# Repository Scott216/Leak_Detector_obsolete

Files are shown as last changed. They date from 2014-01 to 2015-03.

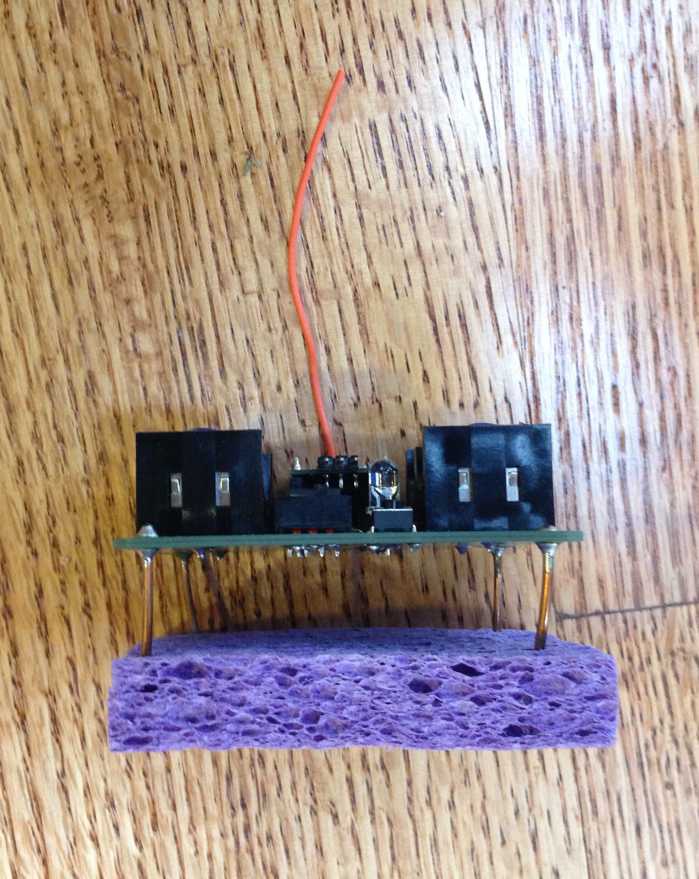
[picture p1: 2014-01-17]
Photos/Leak_Detector 7.jpg

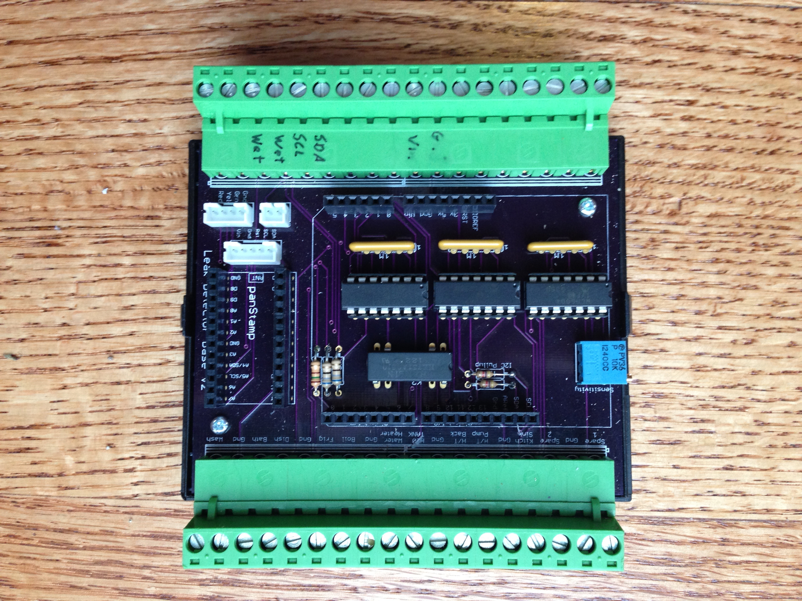
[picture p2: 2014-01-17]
Photos/Leak_Detector 4.jpg

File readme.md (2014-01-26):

This project detects water and sends out  Tweet if water is detected.  The main boards is an Arduino Leonardo with an Ethernet Shield.  The moisture sensors are hard-wired to the PCB.  When hard wiring is not practical, it uses a couple of Panstamps which provide wireless communication.  A Panstamp is basically and Arduino Pro-mini with a wireless radio.  

I chose Leonardo because I needed an Arduino without the headers installed.  The Ethernet shield is actually soldered to the Leonardo with the Ethernet Shield's pins sticking through the Leonardo.  They are still plenty long enough so the Leonardo/Ethernet sandwich can be plugged into the headers on the PCB.

To make the water detector sensor, take a dried out sponge and insert two 14 GA solid copper wires, about an inch apart.  I like to cut copper wire at an angle so it forms a sharp point - this makes it easier to insert into the sponge.  Use small gauge stranded wire to connect the sponge to terminal strip. When sponge is dry it appears as an open circuit. When wet it's varies from 30k to 300k ohms.  I have [sample op-amp circuit](https://www.circuitlab.com/circuit/ayhr2v/water-detector-v2/) circuitlab.com.

Use a MCP6004 Op Amp. Need the Op-amp because the impedance of the sponge is high and you get false readings if you wire directly to an Arduino. I'm using the op amp as a comparator.

Main board leak detector BOM

    1x OKW Enclosure B6504112 $9.77
        PCB Board specs 3.87" x 3.22". position screw terminal holes 0.27" from edge
        2x M2.5 x 6mm Screws to mount PCB to OKW Enclosure
        2x 18 position plug header, PCB Side CTB9358/18AO $2.14
        2x 18 Position screw terminal CTB9208/18 $5.84 
    1x Arduino Leonardo - without headers
    1x Ethernet Shield]
    1x panStamp - http://www.panstamp.com/products/wirelessarduino
    1x JST PH 5-position header P/N B5B-PH-K-S, Digikey 455-1707-ND for OLED Display, (JST Data Sheet)
    1x JST PH 5-wire cable Sparkfun PRT-09917, JST # PHR-5, Crimp pin SPH-002T-P0.5S
    1x JST PH 4-position header P/N B4B-PH-K-S, Digikey 455-1706-ND for LEDs
    1x JST PH 4-wire cable Sparkfun PRT-09916, JST # PHR-4, Crimp pin SPH-002T-P0.5S
    1x JST PH 2-position header P/N B2B-PH-K-S, Digikey 455-1704-ND for on-off switch
    1x JST PH 2-wire cable Sparkfun PRT-09914, JST # PHR-2, Crimp pin SPH-002T-P0.5S
    1x OLED 128 x 32 I2C Display, Adafruit 931
    1x Reed Relay, Hamlin HE751A0510, Digikey HE124-ND
    3x MCP6004 Op amp Digikey MCP6004-I/P-ND
    3x Resistor network 1MΩ Bourns P/N 4606X-101-105LF, Digikey 4606X-1-105LF-ND. (cut off lead on pin 6)
    2x 330Ω 1/4 watt resistors
    2x 4.7kΩ 1/4 watt resistors
    2x 68Ω 1/4 watt resistors
    1x 150Ω 1/4 watt resistor
    1x 10k trimmer Pot,Digikey 490-2856-ND
    1x On-Off Switch, CW Industries P/N GPB040B05BR, Digikey SW632-ND
    1x Yellow LED 2 volts, 20 mA, Bivar P/N PM3YDW12.0, Digikey 492-1617-ND
    1x Red LED 2.1 volts, 20 mA, Bivar P/N PM3RDW12.0, Digikey 492-1616-ND
    1x Green LED 2.1 volts, 20 mA, Bifar P/N PM3GDW12.0, Digikey 492-1612-ND
    1x 10-pin Header for Leonardo, Digikey S7043-ND
    2x 8-pin Header for Leonardo, Digikey S7041-ND
    1x 6-pin Header for Leonardo, Digikey S7039-ND
    2x 12-pin Headers for panStamp, Digikey S7045-ND 

Remote Wireless Detector BOM

    1 MCP601 Op Amp Digikey MCP601-I/P-ND
    8 pin DIP socket Sparkfun PRT-07937
    2 Battery Holders, Digikey 708-1412-ND
    2 CR123 batteries
    1 470k ohm resistor
    1 Panstamp
    1 slide switch Sparkfun COM-00102
    2 5.6 ohm resistor for green & blue led in RGB LED
    1 68 ohm resistor for for red in RGB LED
    1 RGB LED Sparkfun COM-00105
    1 Pushbutton switch, Sparkfun COM-00097
    1 OneWire temp sensor DS18B20
    2 12-pin headers for PanStamp

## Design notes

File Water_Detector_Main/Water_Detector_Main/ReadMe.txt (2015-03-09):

The sketch gets time from an NPT server.  Water detect notifications and low battery are sent out via Twitter.

See this Arduino Thread forum on a discussion on reading inputs and using an Op Amp 
  http://arduino.cc/forum/index.php/topic,90671.msg682130.html#msg682130

I2C Data packet structure
byte 0: panStamp Tx ID
byte 1: Tx online: 0 = offline, 1 = online
byte 2: Wet/Dry Status: 0 = Dry, 1 = Wet
byte 3-4: temperature F
Byte 5-6: battery voltage (millivolts)
Byte 7-8: Spare
Byte 9: checksum

Put sensors in a class.  One class for sensors, then a wired subclass and wireless subclass
Create an array of class objects

Properties:
 For both wired and wireless
   Is wet input - live wet/dry status
   Is wet status - used to trigger dry to wet transition
   Is wet output - wet dry status after some delay
   Name - character array of sensor location, this text can be used for messages on OLED and twitter
   Dry out delay - timer used to let sponge dry out.  Elimantes cycling when sponge is drying out
   Wet delay - delay used to make sure sponge is really wet.  Elimantes cycling when sponge first gets wet
   
 For wireless only:
   Tx Address
   Tx is online
   Temperature
   Battery volts
   Flag - low volts message
   Flag - low temp message
   Flag - sensor offline message

Methods/Actions
  For both wired and wireless
    Send message when water is detected
    Send message when sponge dries up

  For wireless only
    Send message if Tx is offline
    Send messaeg if Tx goes back online
    Send message if battery is low
    Send message if temp is low
    Send message for weekly heartbeat

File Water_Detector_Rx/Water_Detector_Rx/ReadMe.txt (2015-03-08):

Water_Detector_Rx

The receiving panStamp is communicating with the Leonardo via I2C.  The Leonardo is the master and will make a request for the data.  The panStamp will then transmit this as one long array of bytes. Sketch is using DSS's I2C.h library for the I2C master, not Wire.h library.

I2C Data packet structure
byte 0: panStamp Tx ID
byte 1: Tx online: 0 = offline, 1 = online
byte 2: Wet/Dry Status: 0 = Dry, 1 = Wet
byte 3-4: temperature F
Byte 5-6: battery voltage (millivolts)
Byte 7-8: Spare
Byte 9: checksum

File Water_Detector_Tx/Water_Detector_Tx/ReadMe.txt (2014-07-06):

Water_Detector_Tx

A panStamp should be able to run for a couple months on one CR123 battery. 

The panStamps transmit wet/dry status, their ID, battery voltage and temperature.

They sleep for 8 seconds, wake up for 1/2 second to transmit, then repeat.

Simple panStamp test - doesn't use SWAP protocal
Source: http://www.panstamp.org/forum/showthread.php?tid=22

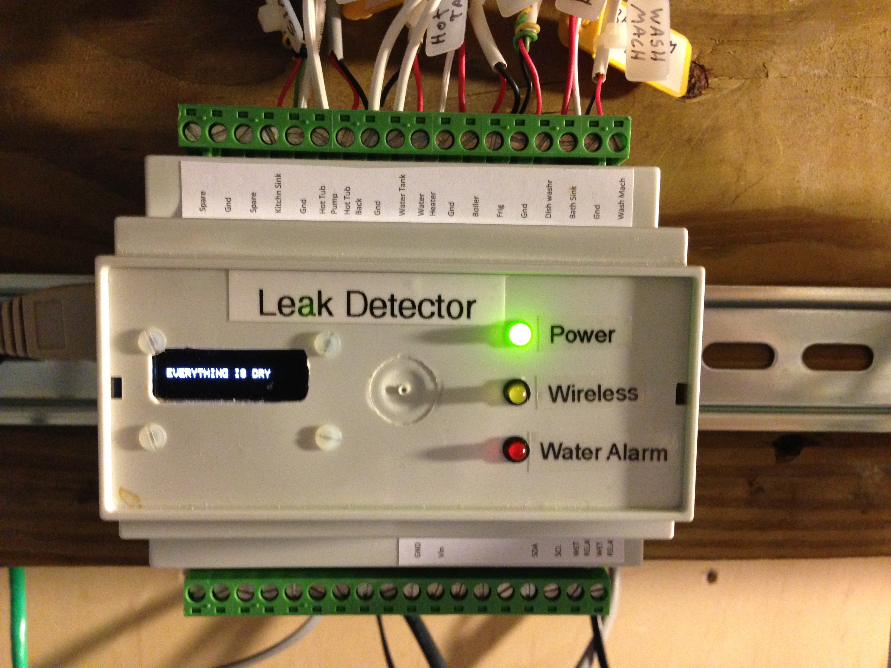
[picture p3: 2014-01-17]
Photos/Leak_Detector 3.jpg

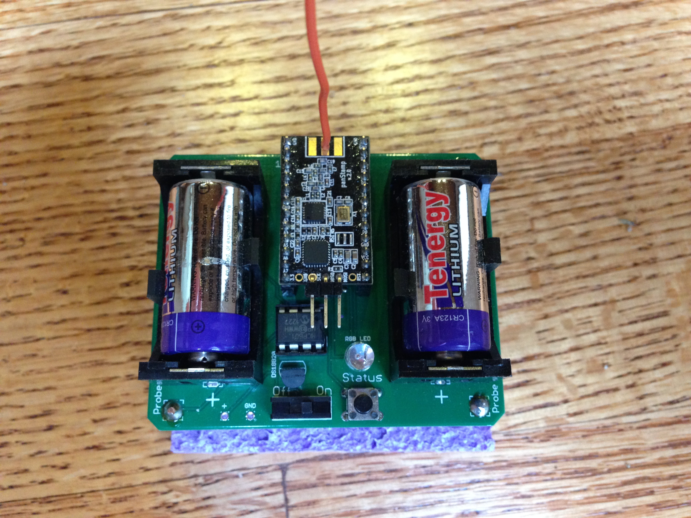
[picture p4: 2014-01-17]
Photos/Leak_Detector 8.jpg

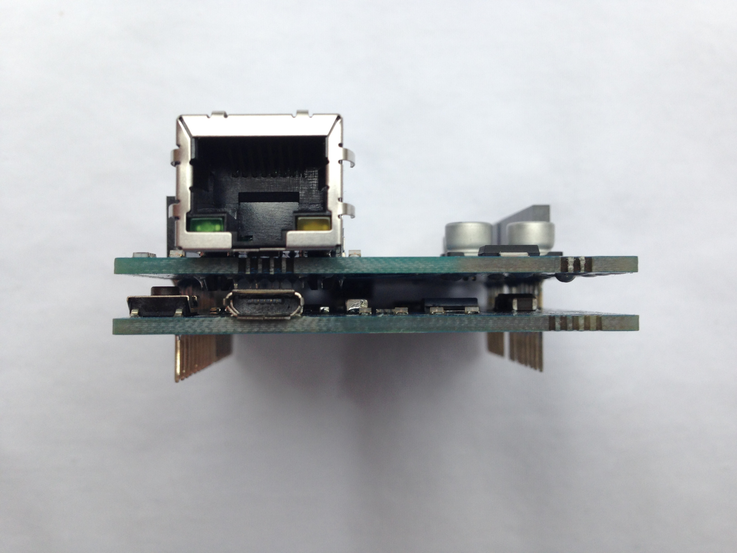
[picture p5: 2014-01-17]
Photos/Leak_Detector 2.jpg

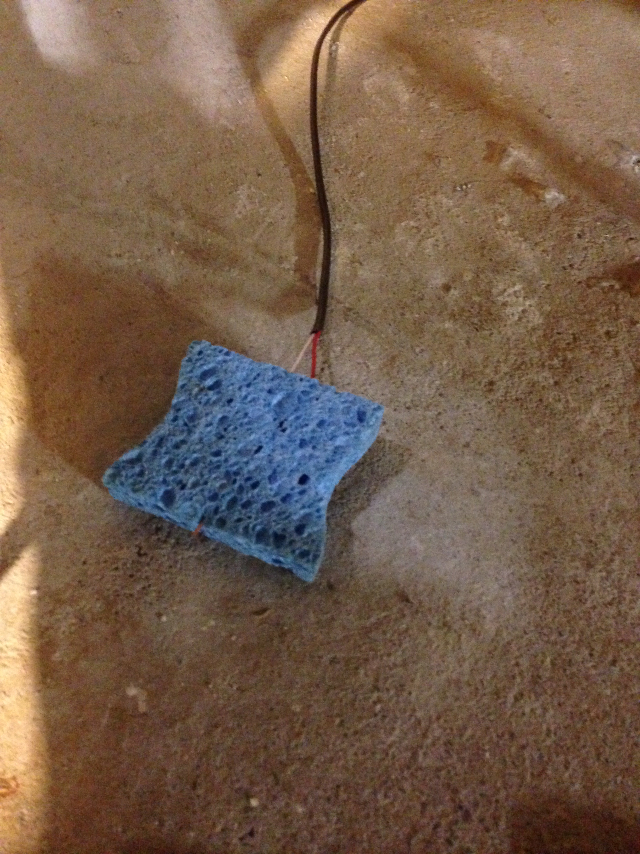
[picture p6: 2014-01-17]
Photos/Leak_Detector 6.jpg

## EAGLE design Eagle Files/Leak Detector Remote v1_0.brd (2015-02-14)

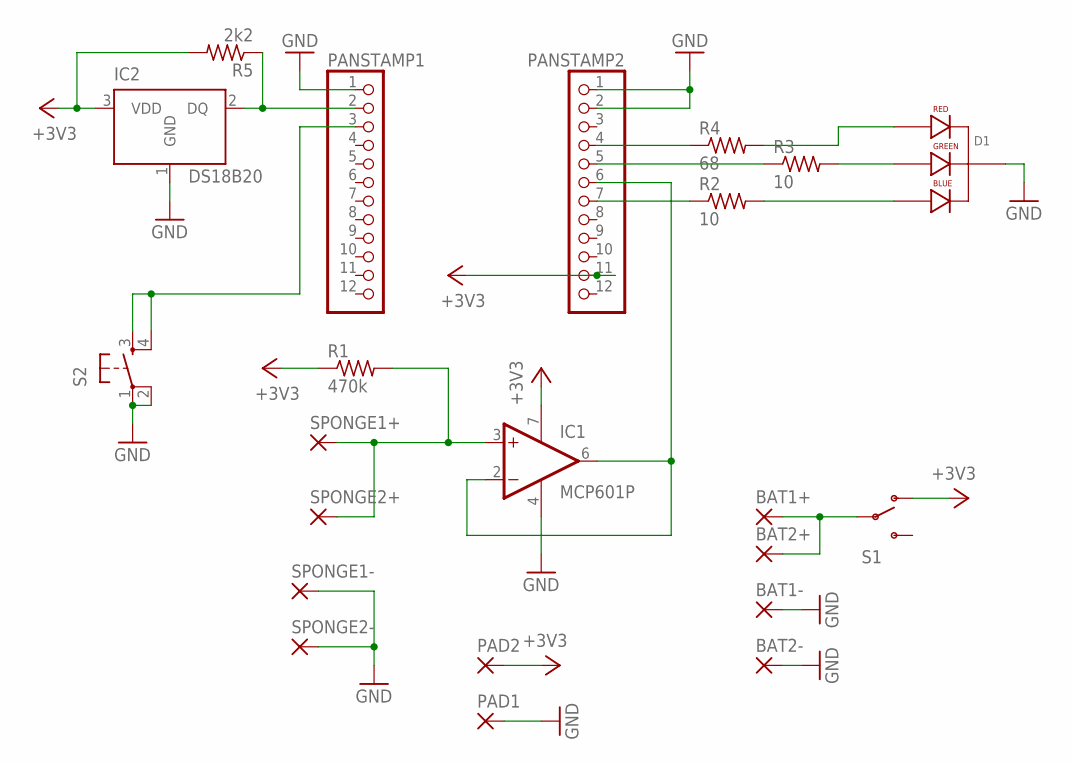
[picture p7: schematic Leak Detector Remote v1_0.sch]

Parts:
BAT1+, BAT1-, BAT2+, BAT2-: 3,81/1,4
D1: LED-RGB-CC-THRUCLEAR; LED-RGB-THRU
IC1: MCP601P; DIL08
IC2: DS18B20; TO-92
PAD1, PAD2: 1,6/0,9
PANSTAMP1, PANSTAMP2: PINHD-1X12; 1X12
R1: 470k; 0204/7
R2, R3: 10; 0204/7
R4: 68; 0204/7
R5: 2k2; 0204/7
S1: SWITCH-SPDTKIT; SWITCH-SPDT_KIT
S2: TAC_SWITCHPTH; TACTILE-PTH
SPONGE1+, SPONGE1-, SPONGE2+, SPONGE2-: 3,81/1,4

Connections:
+3V3: IC1.7 (V+), IC2.3 (VDD), PAD2.1, PANSTAMP2.11, R1.1, R5.2, S1.1 (O)
D3: PANSTAMP2.7, R2.1
D4: IC1.2 (-IN), IC1.6 (OUT), PANSTAMP2.6
D5: PANSTAMP2.5, R3.1
D6: PANSTAMP2.4, R4.1
D8: IC2.2 (DQ), PANSTAMP1.2, R5.1
D9: PANSTAMP1.3, S2.3, S2.4
GND: BAT1-.1, BAT2-.1, D1.2 (CATHODE), IC1.4 (V-), IC2.1 (GND), PAD1.1, PANSTAMP1.1, PANSTAMP2.1, PANSTAMP2.2, S2.1, S2.2, SPONGE1-.1, SPONGE2-.1
unnamed: IC1.3 (+IN), R1.2, SPONGE1+.1, SPONGE2+.1
unnamed: BAT1+.1, BAT2+.1, S1.2
unnamed: D1.1 (RED_CATHODE), R4.2
unnamed: D1.3 (GREEN_CATHODE), R3.2
unnamed: D1.4 (BLUE_CATHODE), R2.2

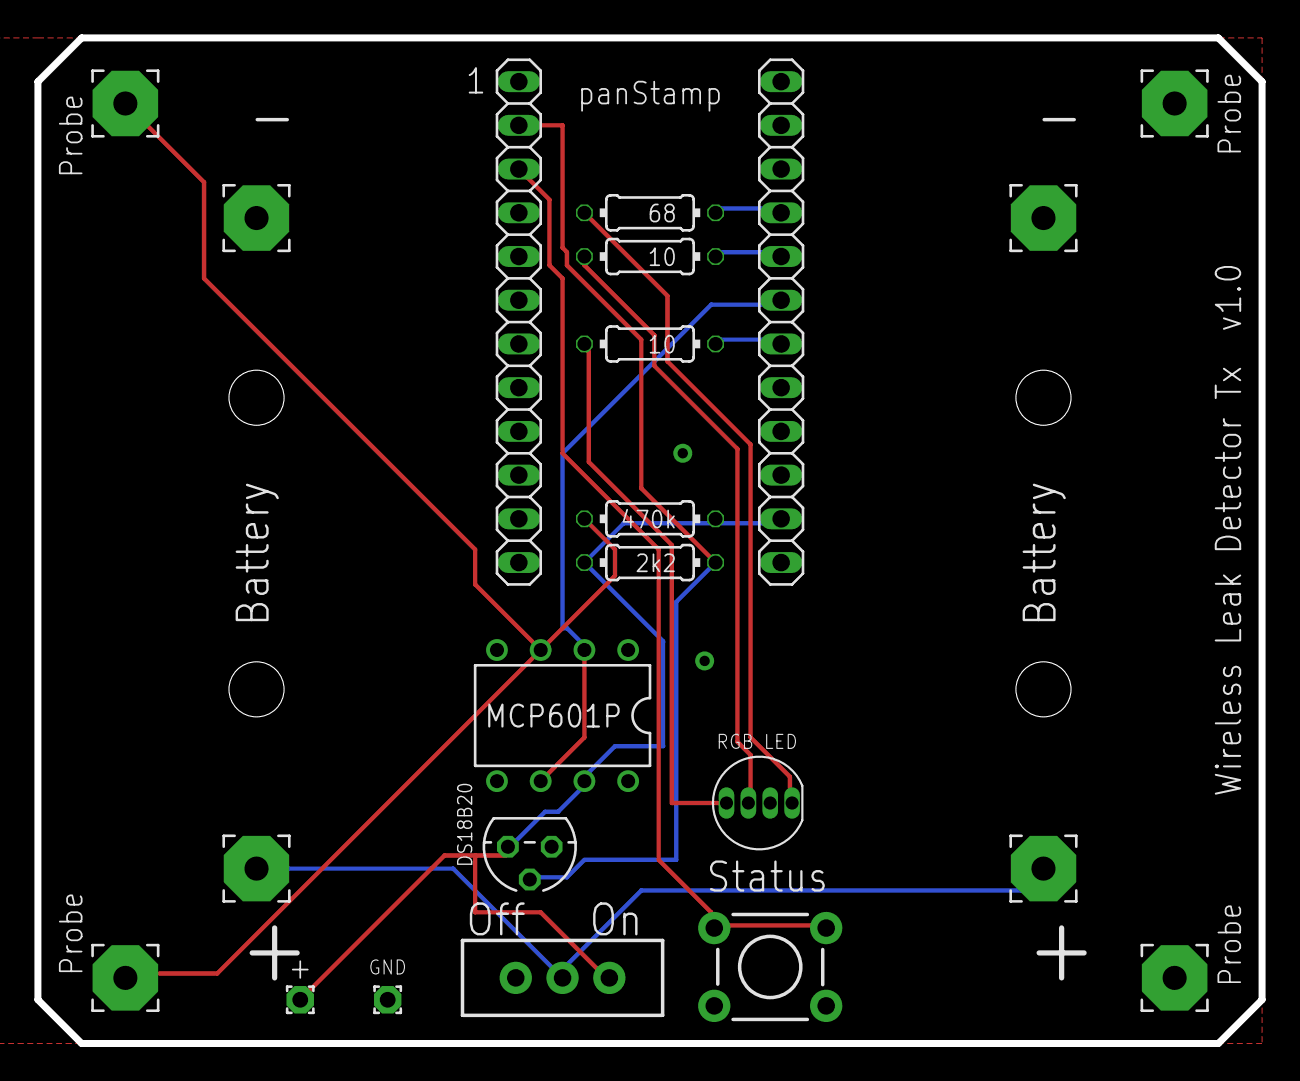
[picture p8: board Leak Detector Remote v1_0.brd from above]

Board: 2 copper layers, 71.1 x 58.4 mm, 22 parts (0 on the bottom side), 13 nets.

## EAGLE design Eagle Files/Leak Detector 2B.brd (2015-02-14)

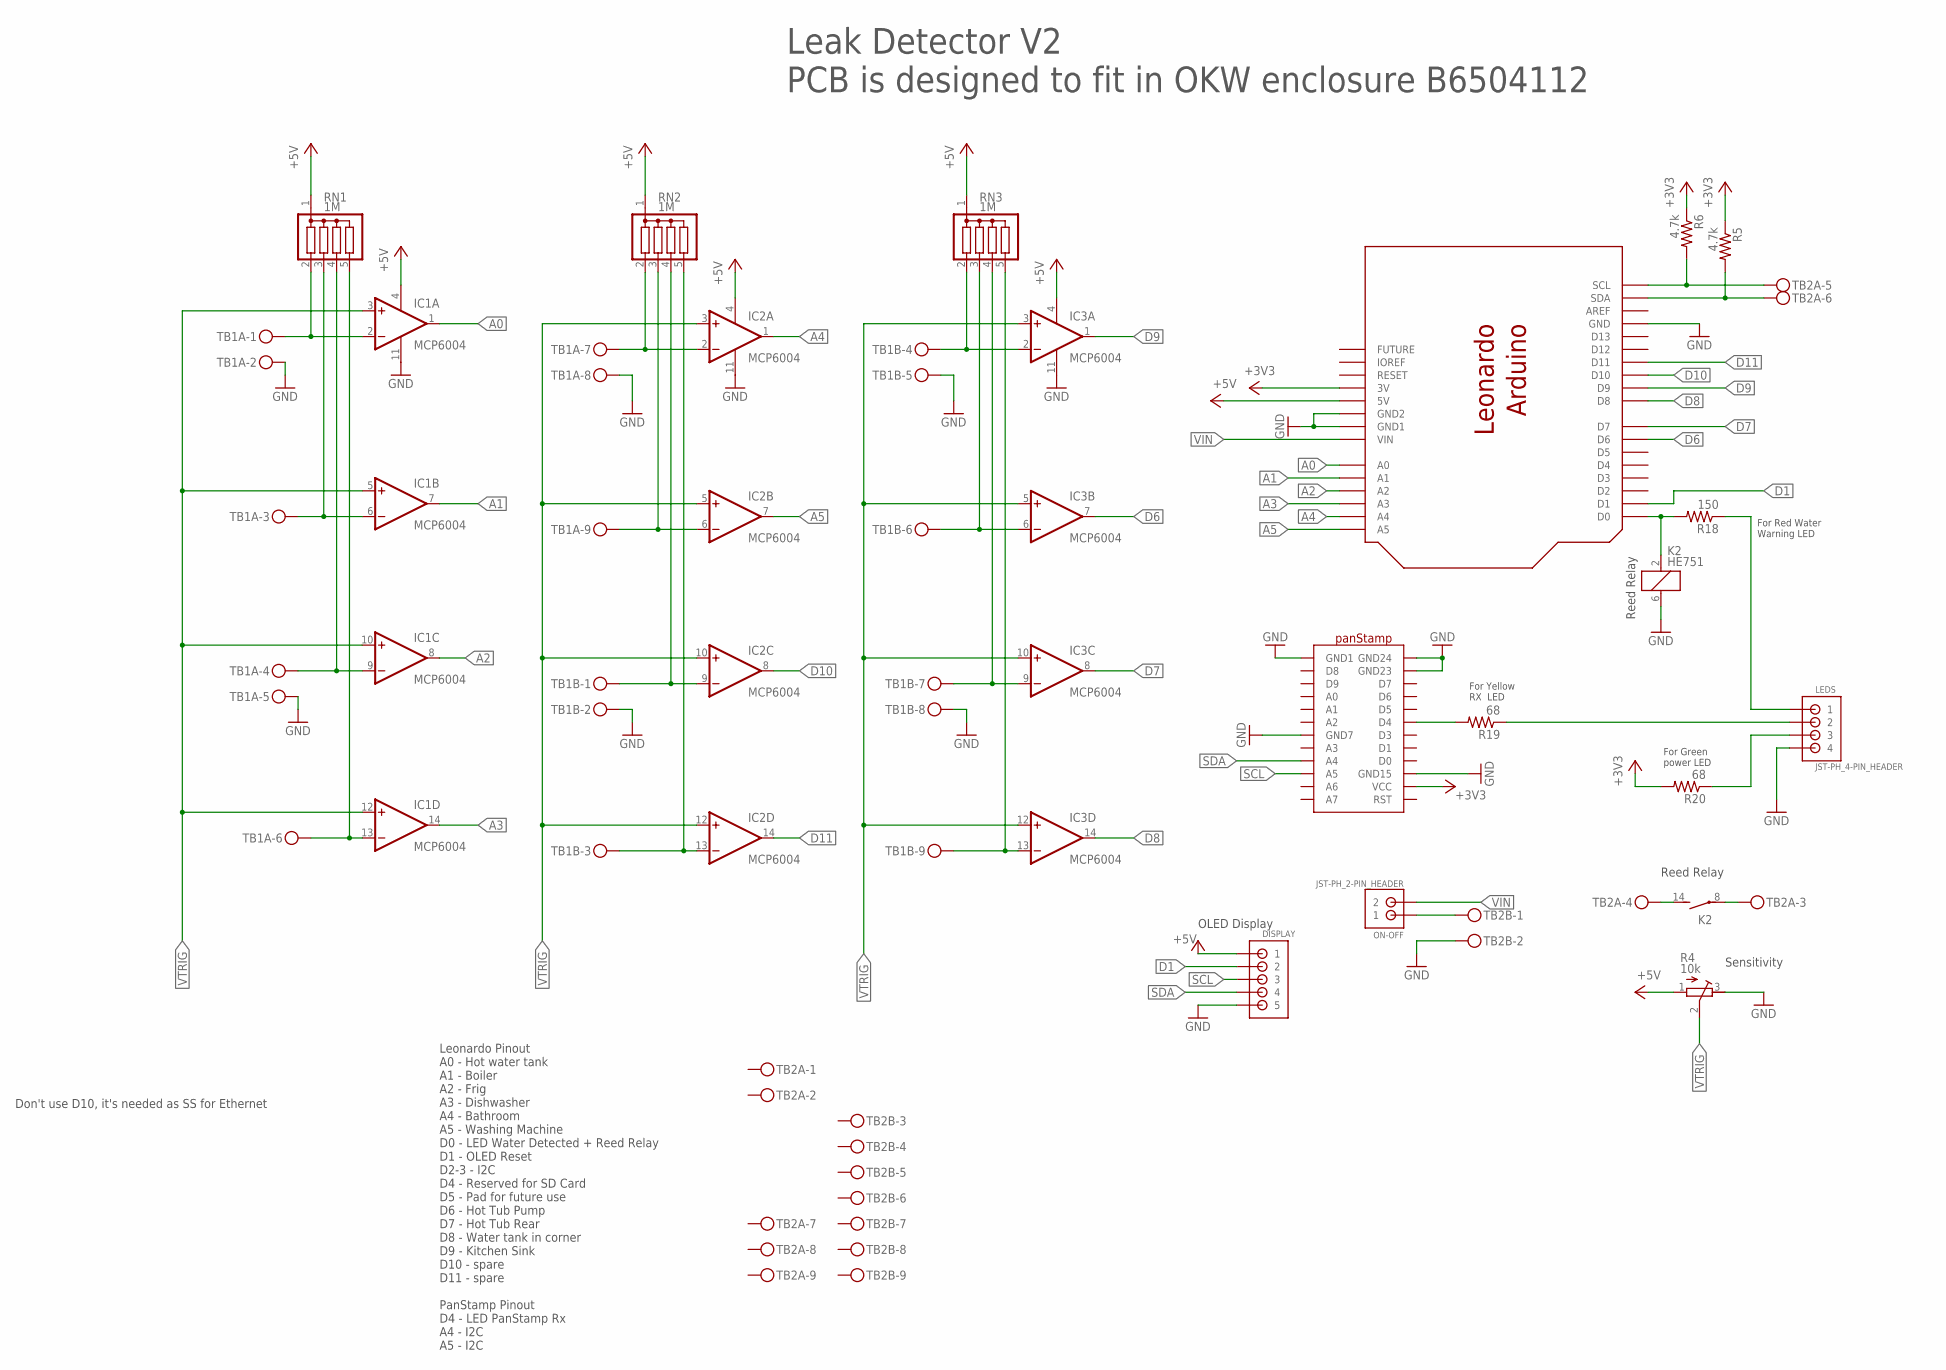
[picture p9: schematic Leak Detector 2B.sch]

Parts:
DISPLAY: JST-PH_5-PIN_HEADER; JST_B5B-PH_HEADER
IC1, IC2, IC3: MCP6004; DIL14
K2: HE751
LEDS: JST-PH_4-PIN_HEADER; JST_B4B-PH_HEADER
ON-OFF: JST-PH_2-PIN_HEADER; JST_B2B-PH_HEADER
R4: 10k; RTRIM3296P
R5, R6: 4.7k; 0207/10
R18: 150; 0207/10
R19, R20: 68; 0207/10
RN1, RN2, RN3: 1M; SIL5
TB1A, TB1B, TB2A, TB2B: MKDSN1,5/9-5,08
U$1: ARDUINO_LEONARDO
U$2: PANSTAMP

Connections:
+3V3: R5.1, R6.1, R20.2, U$1.3V, U$2.VCC
+5V: DISPLAY.P1 (1), IC1.4 (V+), IC2.4 (V+), IC3.4 (V+), R4.1 (E), RN1.1, RN2.1, RN3.1, U$1.5V
A0: IC1.1 (OUT), U$1.A0
A1: IC1.7 (OUT), U$1.A1
A2: IC1.8 (OUT), U$1.A2
A3: IC1.14 (OUT), U$1.A3
A4: IC2.1 (OUT), U$1.A4
A5: IC2.7 (OUT), U$1.A5
BATHROOM: IC2.2 (-IN), RN2.2, TB1A.7
BOILER: IC1.6 (-IN), RN1.3, TB1A.3
D1: DISPLAY.P2 (2), U$1.D1
D6: IC3.7 (OUT), U$1.D6
D7: IC3.8 (OUT), U$1.D7
D8: IC3.14 (OUT), U$1.D8
D9: IC3.1 (OUT), U$1.D9
D10: IC2.8 (OUT), U$1.D10
D11: IC2.14 (OUT), U$1.D11
DISHWASHER: IC1.13 (-IN), RN1.5, TB1A.6
FRIG: IC1.9 (-IN), RN1.4, TB1A.4
GND: DISPLAY.P5 (5), IC1.11 (V-), IC2.11 (V-), IC3.11 (V-), K2.6 (2), LEDS.P4 (4), R4.3 (A), TB1A.2, TB1A.5, TB1A.8, TB1B.2, TB1B.5, TB1B.8, TB2B.2, U$1.GND, U$1.GND$2 (GND2), U$1.GND$3 (GND1), U$2.GND1, U$2.GND7, U$2.GND15, U$2.GND23, U$2.GND24
HAVEPOWER: LEDS.P3 (3), R20.1
HOT_TUB_PUMP: IC3.6 (-IN), RN3.3, TB1B.6
HOT_TUB_REAR: IC3.9 (-IN), RN3.4, TB1B.7
HOT_WATER_TANK: IC1.2 (-IN), RN1.2, TB1A.1
ISWATER: LEDS.P1 (1), R18.1
unnamed: ON-OFF.P1 (1), TB2B.1
unnamed: K2.2 (1), R18.2, U$1.D0
unnamed: K2.14 (S), TB2A.4
unnamed: K2.8, TB2A.3
unnamed: R19.2, U$2.D4
RXOK: LEDS.P2 (2), R19.1
SCL: DISPLAY.P3 (3), R6.2, TB2A.5, U$1.SCL, U$2.A5
SDA: DISPLAY.P4 (4), R5.2, TB2A.6, U$1.SDA, U$2.A4
SINK: IC3.2 (-IN), RN3.2, TB1B.4
SPARE1: IC2.9 (-IN), RN2.4, TB1B.1
SPARE2: IC2.13 (-IN), RN2.5, TB1B.3
VIN: ON-OFF.P2 (2), U$1.VIN
VTRIG: IC1.3 (+IN), IC1.5 (+IN), IC1.10 (+IN), IC1.12 (+IN), IC2.3 (+IN), IC2.5 (+IN), IC2.10 (+IN), IC2.12 (+IN), IC3.3 (+IN), IC3.5 (+IN), IC3.10 (+IN), IC3.12 (+IN), R4.2 (S)
WASH_MACH: IC2.6 (-IN), RN2.3, TB1A.9
WATER_TANK: IC3.13 (-IN), RN3.5, TB1B.9

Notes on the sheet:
Leonardo Pinout A0 - Hot water tank A1 - Boiler A2 - Frig A3 - Dishwasher A4 - Bathroom A5 - Washing Machine D0 - LED Water Detected + Reed Relay D1 - OLED Reset D2-3 - I2C D4 - Reserved for SD Card D5 - Pad for future use D6 - Hot Tub Pump D7 - Hot Tub Rear D8 - Water tank in corner D9 - Kitchen S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
Leak Detector V2 PCB is designed to fit in OKW enclosure B6504112
OLED Display
Reed Relay
Sensitivity
For Green power LED
For Yellow RX LED
For Red Water Warning LED
Don't use D10, it's needed as SS for Ethernet

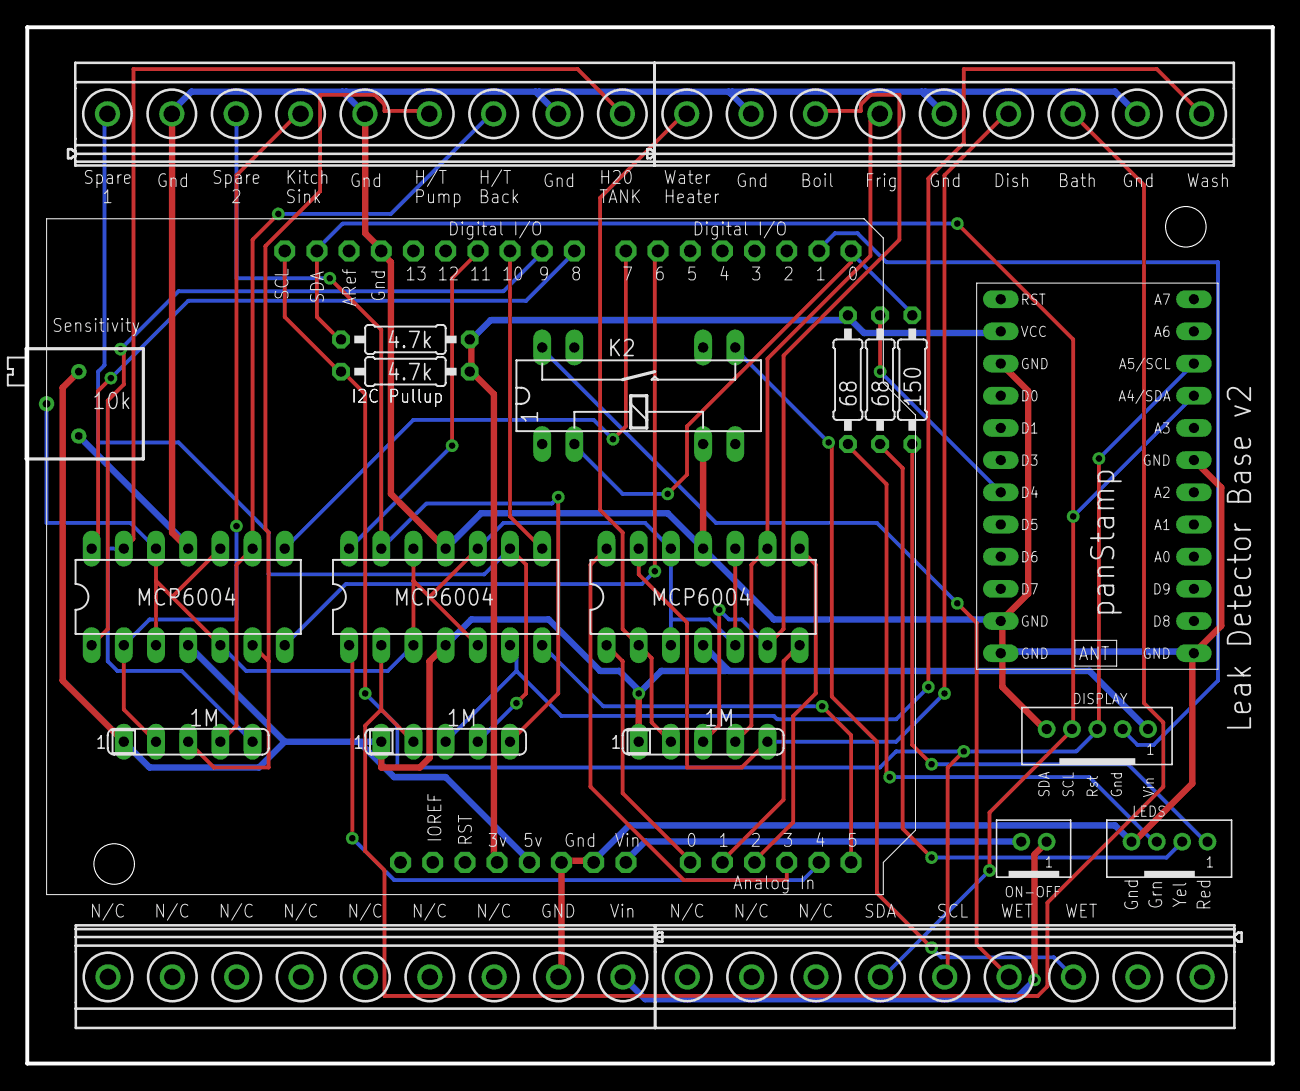
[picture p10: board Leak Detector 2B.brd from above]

Board: 2 copper layers, 98.3 x 81.8 mm, 22 parts (0 on the bottom side), 40 nets.

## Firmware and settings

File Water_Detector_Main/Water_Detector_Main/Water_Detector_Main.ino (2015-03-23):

/*  
See Readme.txt file
directory /Dropbox/Arduino/Water_Detector/ 
Board: Leonardo
Not much memory left 

To do:
Make a class library and have each instance trigger actions instead of looping through arrays - maybe
setupNTPTime() always returns true, see if you can return actual state of ethernet connection
See if you can save memory by using http://github.com/nomadnt/uHTTP
Consider replacing Twitter with Tropo.com SMS service
 
 
Change Log
05/28/14 v2.00 - Changed low temp alarm logic so it only sends low temp tweet if voltage > 2500 mA.  Get false alarms when
                 voltage is below this
06/27/14 v2.01 - Updated tx offline message to display hrs or sec depending on how long it was offline.  Fixed
                 updateOledDisplay so Tx offline messages would display
07/04/14 v2.02 - Added checksum to data packet, renamed some constants
07/05/14 v2.03 - Changed NTP update. It was updating every time you checked sensors and every 48 hours.  Changed to check once a minutes
07/30/14 v2.04 - Added ability to print version if a "v" is typed into serial monitor
12/18/14 v2.05 - Added return to setupNTPTime().  Made sendNTPpacket() void instead of unsigned long
01/09/15 v2.06 - Renamed constant for RED led output to PIN_ALARM
01/12/15 v2.07 - Fixed Sunday heartbeat alert, I hope.  Compiled size (v1.0.5) 27,372/28,672 bytes
02/10/15 v2.08 - Added dehumidifier.  Changed TBD2 to DEHUMIDIFIER.  Size (IDE 1.0.5) 27,390 / 28,672 bytes
02/14/15 v2.09 - Removed printStates().  Size (IDE 1.0.5) 27,276 / 28,672 bytes
02/27/15 v3.00 - Changed I2C so master requests a specific wireless sensor.  Added 3rd wireless sensor.  Added temperature to Sunday heartbeat alert.
                 Used F() with display.print() for OLED to free up some RAM.  Made an array of struct and got wireless data by looping through array.
03/22/15 v3.01 - Removed code that prints version # if the letter v is typed into serial moniitor.  IDE 1.6.0 compile size 27,070
*/

#define VERSION "v3.01"
// #define PRINT_DEBUG      // Comment this out to turn off verbose printing

#include <HardwareSerial.h>
#include <SPI.h>             // Allows you to communicate with SPI devices. See: http://arduino.cc/en/Reference/SPI
#include <Ethernet.h>        // http://arduino.cc/en/Reference/Ethernet
#include <Twitter.h>         // http://arduino.cc/playground/Code/TwitterLibrary
#include <I2C.h>             // http://dsscircuits.com/index.php/articles/66-arduino-i2c-master-library  https://github.com/DSSCircuits/I2C-Master-Library
#include <Tokens.h>          // Contains Twitter token
#include <Adafruit_GFX.h>    // For OLED display http://github.com/adafruit/Adafruit-GFX-Library
#include <SSD1306_I2C_DSS.h> // For OLED display http://github.com/Scott216/SSD1306_I2C_DSS
#include "Water_Detector_Main_Library.h"  // Include application, user and local libraries


// This gets rid of compiler warning: Only initialized variables can be placed into program memory area
#undef PROGMEM
#define PROGMEM __attribute__(( section(".progmem.data") ))

byte mac[] = { 0x90, 0xA2, 0xDA, 0xEF, 0x46, 0x81 };
byte ip[] =  { 192, 168, 46, 81 };

// Analog inputs 0 & 1 are configured as Digitol I/O.
//      Name              I/O    Description
#define PIN_ALARM           0   // Turns on red LED and relay
#define OLED_RESET          1
// Reserved                 2      I2C
// Reserved                 3      I2C
// Reserved                 4      SD Card
//                          5      Unused
#define HOTTUBFILTER        6   // Sponge in crawlspace by hot tub filter and pump
#define HOTTUBBACK          7   // Sponge in crawlspace behind hot tub
#define WATERTANK           8   // Sponge in crawlspace corner by water tank
#define KITCHENSINK         9   // Sponge under kitchen sink
// reserved                10   // Slave select
#define DEHUMIDIFIER       11   // Dehumidifier
#define TBD1               12   // Future Use
#define WATERHEATER        A0   // Sponge under hot water heater
#define BOILER             A1   // Sponge next to boiler
#define FRIG               A2   // Sponge behind refrigerator
#define DISHWASHER         A3   // Sponge behind dishwasher
#define FIRSTFLOORBRSINK   A4   // Sponge in first floor bathroom sink
#define WASHINGMACH        A5   // Sponge next to washing machine

#define WET HIGH       // When a sponge is wet, the digital input is HIGH
#define DRY LOW        // When a sponge is dry, the digital input is LOW

const uint32_t MINUTE  =                   60000;  // milliseconds in a minute
const uint32_t DOUBLE_CHECK_DELAY =   2 * MINUTE;  // Delay after sensor first detects water to check again after a few minutes
const uint32_t DRYING_DELAY =       180 * MINUTE;  // 3 hour delay when sponges are drying out before twitter it is updated. Prevents extra alerts from going out

const uint8_t ADDR_I2C_OLED  =     0x3C;  // OLED Display I2C address
const uint8_t ADDR_I2C_SLAVE =       21;  // I2C Slave address of panStamp Rx
const uint8_t ADDR_BATH_MASTER =      0;  // panStamp device address for 2nd floor master bathroom  // SRG: Change addresses to 0,1,2
const uint8_t ADDR_BATH_GUEST =       1;  // panStamp device address for 2nd floor guest bathroom
const uint8_t ADDR_BATH_FIRST =       2;  // panStamp device address for 1st floor bathroom
const uint8_t NUM_SENSORS_WIRELESS =  3;  // number of wireless water sensors
const uint8_t NUM_SENSORS_WIRED =    12;  // Number of wired water detector inputs
const uint8_t DATA_LENGTH_I2C =      10;  // Packets sent by each panStamp
bool       g_isAnythingWet =      false;  // Flags if anything is wet


// Use arrays to hold input status.  Total number of inputs are wired plus wireless sensors
bool  InputState[NUM_SENSORS_WIRED + NUM_SENSORS_WIRELESS];     // Input reading, HIGH when water is present LOW when it's not
bool WaterDetect[NUM_SENSORS_WIRED + NUM_SENSORS_WIRELESS];     // Sensor state after delay to make sure it's really wet or dry
uint32_t weeklyHeartbeatTimer = 0;                              // mS until Sunday at noon, at which time a tweet will go out to verify sketch is still running  static uint8_t TweetCounter;  // prevent tweets from getting to high

// Define typedef structurs for wireless sensors.  typedef struct definition is in LocalLibrary.h
RemoteSensorData_t g_wirelessSensor[NUM_SENSORS_WIRELESS];  // array for wireless sensors

// Token for Twitter Account
Twitter twitter(TWITTER_TOKEN);

// Put input pin numbers in array so you can use loops to read wired inputs
uint8_t InputPinNum[] = { FIRSTFLOORBRSINK, WASHINGMACH, TBD1, DEHUMIDIFIER, WATERHEATER, BOILER, FRIG, DISHWASHER, KITCHENSINK, HOTTUBFILTER, HOTTUBBACK, WATERTANK };


// Function Prototypes
bool     ReadRFSensors(RemoteSensorData_t* rfsensor);
void     SendAlert(byte SensorArrayPosition, bool IsWet);
void     ProcessSensors(void);
int16_t SendTweet(char msgTweet[]);
uint32_t getMsUntilSundayNoon(uint8_t *ntpTime);  // mS until Sunday noon - for weeklyheartbeat timer
void     software_Reset();
bool     setupNTPTime();
bool     getTime(uint8_t *ntpTime);
void     parseTimePacket(uint8_t *ntpTime);
void     sendNTPpacket(IPAddress& address);
void     updateOledDisplay();
bool     sundayHeartbeatMsg(); // sends twitter message Sunday at noon with info from wireless sensors

// NPT servers work as of 4/17/13
// List of servers: http://tf.nist.gov/tf-cgi/servers.cgi
// don't query more then 4 seconds
IPAddress timeServer1( 216, 171, 112,  36); 
IPAddress timeServer2( 206, 246, 122, 250);
IPAddress timeServer3( 64,   90, 182,  55);  

const uint8_t NTP_PACKET_SIZE= 48;       // NTP time stamp is in the first 48 bytes of the message
      uint8_t packetBuffer[NTP_PACKET_SIZE];      //buffer to hold incoming and outgoing packets
      uint8_t ntpTime[6];

// A UDP instance to let us send and receive packets over UDP
EthernetUDP Udp;

// Instantiate OLED dispplay object
Adafruit_SSD1306 display(OLED_RESET);


//=========================================================================================================================
//=========================================================================================================================
void setup ()
{  
  Serial.begin(9600);
  #ifdef PRINT_DEBUG
    while (!Serial && millis() < 6000) {}  // for Leonardo wait here for a few seconds for serial monitor connection
    Serial.print(F("Leak Detecter "));
    Serial.println(VERSION);
  #endif

  // Start I2C communication
  I2c.begin();
  I2c.timeOut(30000);  // set I2C timeout to 30 seconds
  I2c.pullup(0);       // disable internal pullup resistors on I2C pins, don't want to pull-up to 5 volts because of panStamp

  // Initialize OLED displey
  display.begin(SSD1306_SWITCHCAPVCC, ADDR_I2C_OLED);  
  display.clearDisplay();  
  display.setTextColor(WHITE);
  display.setTextSize(1);
  display.setCursor(0,10);
  display.print(F("Leak Detect "));
  display.println(VERSION);
  display.display();
  
  // Initialize Ethernet connection and UDP
  bool EthernetOK = setupNTPTime();
  delay(2000);
  if(EthernetOK)
  {
    // Get the NTP Time
    if( getTime(ntpTime) )
    {
      // Set weekly countdown timer - Sunday noon
      weeklyHeartbeatTimer = millis() + getMsUntilSundayNoon(ntpTime);
      #ifdef PRINT_DEBUG
        Serial.print(F("hours until Sunday noon = "));
        Serial.println(weeklyHeartbeatTimer / (MINUTE * 60UL));
      #endif  
    }
    else
    { 
      #ifdef PRINT_DEBUG
        Serial.println(F("Failed to get NTP time in setup()")); 
      #endif
    }
  }
  
  
  for(int i = 0; i < NUM_SENSORS_WIRED; i++)
  { pinMode(InputPinNum[i], INPUT); }
  pinMode(PIN_ALARM, OUTPUT);  // Alarm output: red LED and reed relay
  digitalWrite(PIN_ALARM, LOW);
  
  // Initialiaze one shot triggers for messages and IDs. 
  for ( byte i=0; i < NUM_SENSORS_WIRELESS; i++)
  {
    g_wirelessSensor[i].lowVoltMsgFlag =           false;
    g_wirelessSensor[i].lowTempMsgFlag =           false;
    g_wirelessSensor[i].txOfflineTimestamp =           0;
    g_wirelessSensor[i].flag_SentMsg_TxIsOffline = false;
    g_wirelessSensor[i].ID = i;  // Sensor ID number is also used as array element number.
  }
  
  char tweetMsg[] = "Leak Detector Restarted";
  SendTweet(tweetMsg);  // Send startup tweet
  
  ProcessSensors();  // Check sensors to see if anything is wet

  display.clearDisplay();
  display.display();

} // end setup()


//=========================================================================================================================
//=========================================================================================================================
void loop ()
{
  static uint32_t CheckSensorsTimer = 0;                // Timer to check the sensors
  static uint32_t checkNtpTimer = millis() +  MINUTE;
  
  if ( (long)(millis() - CheckSensorsTimer) >= 0 )
  {
    display.clearDisplay();    
    display.setCursor(0,10);
    display.println(F("CHECKING SENSORS..."));
    display.display();
    
    ProcessSensors();  // Check sensors to see if anything is wet
    
    updateOledDisplay();
    CheckSensorsTimer = millis() + 1000UL; // add 1 second to timer
  }
  
  sundayHeartbeatMsg();  // sends tweet for each wireless sensor every Sunday at noon 

  // If anything is wet, turn on LED and relay (they are on the same output)
  bool wetOutputState = LOW;
  for(int i = 0; i < NUM_SENSORS_WIRED + NUM_SENSORS_WIRELESS; i++)
  {
    if( WaterDetect[i] == WET )
    { wetOutputState = HIGH; }
  }    
  digitalWrite(PIN_ALARM, wetOutputState);  // turn on red LED and relay if anything is wet

  // Check NTP timer
  if( (long)( millis() -  checkNtpTimer) > 0 )
  {
    if( getTime(ntpTime) )
    { checkNtpTimer = millis() + MINUTE; }
  }
    
}  // end loop()


//=========================================================================================================================
// Check inputs to see if any sponges are wet
//=========================================================================================================================
void ProcessSensors()
{
  char twitterMsgNoName[50];  // Twitter message without the sensor name
  char sensorName[16];        // Sensor name to be used in twitter message
  char twitterMsg[70];        // Twitter message with the sensor name
 
  
  static bool isWet[NUM_SENSORS_WIRED + NUM_SENSORS_WIRELESS];  // Used to trigger if an input goes from Dry to Wet.  Trigger will turn on WaterDetectOutput for 10 seconds.

  g_isAnythingWet = false;  // reset flag
  
  // read hard wired inputs
  for(int i = 0; i < NUM_SENSORS_WIRED; i++)
  {
    // Read hard wired sensors
    // Loop until two consecutive reading are the same.  This helps elimanite bad readings
    bool  firstreading = DRY;
    bool secondreading = DRY;
    do
    {
      firstreading = digitalRead(InputPinNum[i]);
      delay(10);
      secondreading = digitalRead(InputPinNum[i]);
    } while (firstreading != secondreading);
    InputState[i] = firstreading;
    
    if ( InputState[i] == WET )
    { g_isAnythingWet = true; }
  }
  
  // Loop through wireless sensors and get data
  // Send Tweet if anything is wrong
  for (byte ws = 0; ws < NUM_SENSORS_WIRELESS; ws++)
  {
    
    // Sensor name for start of Twitter message
    switch( ws)
    {
      case ADDR_BATH_MASTER:
        strcpy(sensorName, "Master Bath ");
        break;
      case ADDR_BATH_GUEST:
        strcpy(sensorName, "Guest Bath ");
        break;
      case ADDR_BATH_FIRST:
        strcpy(sensorName, "First Fl Bath ");
        break;
      default:
        strcpy(sensorName, "Unknown  ");
        break;
    }
    
    // Get wiresless sensor data
    bool wirelessSensorIsOkay = ReadRFSensors( &g_wirelessSensor[ws]);
    if( wirelessSensorIsOkay )
    {
      
      // If wireless sensor came back online, send a Tweet
      if ( g_wirelessSensor[ws].flag_SentMsg_TxIsOffline == true )  // if this is true, it means sensor is now online, but offline message has been sent.  So now send a back online message
      {
        if ( (millis() - g_wirelessSensor[ws].txOfflineTimestamp) < 10800000UL ) // < 3 hours
        sprintf_P(twitterMsgNoName, PSTR("is back online: %dmV. Offline for %lu sec"), g_wirelessSensor[ws].volts, (millis() - g_wirelessSensor[ws].txOfflineTimestamp) / 1000UL );
        else
        sprintf_P(twitterMsgNoName, PSTR("is back online: %dmV. Offline for %lu hrs"), g_wirelessSensor[ws].volts, (millis() - g_wirelessSensor[ws].txOfflineTimestamp) / 3600000UL );
        strcpy(twitterMsg, sensorName);
        strcat(twitterMsg, twitterMsgNoName);
        SendTweet(twitterMsg);
      }

      g_wirelessSensor[ws].flag_SentMsg_TxIsOffline = false; // reset flag for sending Tweeet about wireless sensor being offline
          
      InputState[NUM_SENSORS_WIRED + ws] = g_wirelessSensor[ws].IsWet;
      if ( g_wirelessSensor[ws].IsWet == WET )
      { g_isAnythingWet = true; }

      // Check for low volts
      if( g_wirelessSensor[ws].online == true && g_wirelessSensor[ws].volts < 2800 && g_wirelessSensor[ws].lowVoltMsgFlag == false)
      {
        sprintf_P(twitterMsgNoName, PSTR("Low Battery: %dmV"), g_wirelessSensor[ws].volts );
        strcpy(twitterMsg, sensorName);
        strcat(twitterMsg, twitterMsgNoName);
        SendTweet(twitterMsg);
        g_wirelessSensor[ws].lowVoltMsgFlag = true;
      }
      // Reset low volts flag if volts is over 3000 mV
      if(g_wirelessSensor[ws].volts > 3000)
      {
        g_wirelessSensor[ws].lowVoltMsgFlag = false;
      }
      
      // Check for low temperature
      if( g_wirelessSensor[ws].online == true && g_wirelessSensor[ws].temp <= 40 && g_wirelessSensor[ws].temp >= 20 && g_wirelessSensor[ws].lowTempMsgFlag == false && g_wirelessSensor[ws].volts > 2500 )
      {
        sprintf_P(twitterMsgNoName, PSTR("Low Temp: %d°F"), g_wirelessSensor[ws].temp);
        strcpy(twitterMsg, sensorName);
        strcat(twitterMsg, twitterMsgNoName);
        SendTweet(twitterMsg);
        g_wirelessSensor[ws].lowTempMsgFlag = true;
      }
      // Reset low temp flag if temp is 50 F
      if(g_wirelessSensor[ws].temp >= 50)
      {
        g_wirelessSensor[ws].lowTempMsgFlag = false;
      }
    }  // end if( wirelessSensorIsOkay )
    else  // didn't get wireless data
    {
      // If wireless sensor is offline, send tweet
      if( g_wirelessSensor[ws].online == false && g_wirelessSensor[ws].flag_SentMsg_TxIsOffline == false )
      {
        strcpy_P(twitterMsgNoName, PSTR("is offline"));
        strcpy(twitterMsg, sensorName);
        strcat(twitterMsg, twitterMsgNoName);
        if( SendTweet(twitterMsg) == 200 )
        { g_wirelessSensor[ws].flag_SentMsg_TxIsOffline = true; }  // set flag so only one Tweet is sent
        g_wirelessSensor[ws].txOfflineTimestamp = millis(); // Time wireless sensor went offline
      }
    }  // finished processing 1 wireless sensor
  
  } // finished processing all wireless sensors
  
  
  // See if any inputs have gone from Dry to Wet
  static uint32_t DoubleCheckTime[NUM_SENSORS_WIRED + NUM_SENSORS_WIRELESS];  // Used to wait a few minutes after a sensor is triggered to check the sensor a 2nd time to see if there is still water. Like button debouncing
  for(int i = 0; i < NUM_SENSORS_WIRED + NUM_SENSORS_WIRELESS; i++)
  {
    if((InputState[i] == WET) && (isWet[i] == DRY ))
    {
      isWet[i] = WET;
      DoubleCheckTime[i] = millis() + DOUBLE_CHECK_DELAY;  // Set time to check again to make sure it's really wet
    }
  } // End check for Dry to Wet
  
  
  // Double check input after a delay to see it it's still wet
  for(int i = 0; i < NUM_SENSORS_WIRED + NUM_SENSORS_WIRELESS; i++)
  {
    if( (isWet[i] == WET) && (WaterDetect[i] == DRY) && ((long)(millis() - DoubleCheckTime[i]) >= 0) )
    {
      WaterDetect[i] = WET;  // Sponge is still wet after delay
      SendAlert(i , WET);    // One of the inputs is still wet after DOUBLE_CHECK_DELAY.  Send Tweet out
     }
  } // End double check for wet sponge
  
  
  // If input is dry, reset WetFlag[]
  // A sponge isn't determined to be dry unless the input has been dry for DRYING_DELAY (3 hours)
  static uint32_t   WetToDryDelay[NUM_SENSORS_WIRED + NUM_SENSORS_WIRELESS];  // Delay used to let sponge dry out before indicating it's dry
  for(int i = 0; i < NUM_SENSORS_WIRED + NUM_SENSORS_WIRELESS; i++)
  {
    if(InputState[i] == DRY)
    { isWet[i] = DRY; }
    else
    { WetToDryDelay[i] = millis() + DRYING_DELAY; } // If input is WET, reset drying delay
  }
  
  // Check for dried out sponge, after long delay
  for(int i = 0; i < NUM_SENSORS_WIRED + NUM_SENSORS_WIRELESS; i++)
  {
    if( (isWet[i] == DRY) && (WaterDetect[i] == WET) && ((long)(millis() - WetToDryDelay[i]) >= 0))
    {
      // Sensor went from Wet To Dry
      WaterDetect[i] = DRY;
      SendAlert(i, DRY);
    }
  } // End Wet to Dry
  
} // end ProcessSensors()


//=========================================================================================================================
// Get the data from wireless sensors
// Returns true if sensor is online and master recieved data, otherwise false
//=========================================================================================================================
bool ReadRFSensors(RemoteSensorData_t* rfsensor)
{
  bool gotI2cPacket = false;  // Flag to indicate I2C packet came in
  const uint8_t CHECKSUMBYTE = DATA_LENGTH_I2C - 1;
  const uint8_t I2C_OKAY = 0;
  
  uint8_t i2cPacketData[DATA_LENGTH_I2C];   // Array to hold wireless sensor data
  
  uint8_t i2cReturnStatus = I2c.write(ADDR_I2C_SLAVE, rfsensor->ID);  // Tell slave which remote sensor data to send back
  delay(10); // Slave needs a little time before next command
  if(i2cReturnStatus == I2C_OKAY)
  {
    i2cReturnStatus = I2c.read(ADDR_I2C_SLAVE, DATA_LENGTH_I2C , i2cPacketData); // gets data from slave for selected remote sensor
    if(i2cReturnStatus == I2C_OKAY)
    {  gotI2cPacket = true; }
  }
  
  // If got I2C packet, then  process it
  if( gotI2cPacket )
  {
    // verify checksum
    byte checksum = 0;
    for (int cs = 0; cs < CHECKSUMBYTE; cs++)
    { checksum += i2cPacketData[cs]; }
    
    if ( i2cPacketData[CHECKSUMBYTE] !=  checksum )  // SRG if checksum is on the left, condition is always true.  Can't reproduce issue in simplified sketch
    {
      // Checksum failed
      #ifdef PRINT_DEBUG
        Serial.println(F("Checksum failed"));
      #endif
      rfsensor->online = false;
      return false;  // exit function
    }
    
    // See if slave returned data from the correct remote and if the remote is online
    bool addressMatches = ( i2cPacketData[0] == rfsensor->ID );
    bool remoteIsOnline = ( i2cPacketData[1] == true );
    if ( addressMatches && remoteIsOnline )
    {
      // Move sensor data from I2C packet to local structure
      rfsensor->ID =     i2cPacketData[0];
      rfsensor->online = i2cPacketData[1];
      rfsensor->IsWet =  i2cPacketData[2];
      rfsensor->temp  =  i2cPacketData[3] << 8;
      rfsensor->temp |=  i2cPacketData[4];
      rfsensor->volts  = i2cPacketData[5] << 8;
      rfsensor->volts |= i2cPacketData[6];
      return true;
    }
    else  // Wrong address ID or remote is offline
    {
      rfsensor->online = false;
      return false;
    }
  }
  else // didn't get I2C packet
  {
    rfsensor->online = false;
    return false;
  }
  
} // end ReadRFSensors()
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

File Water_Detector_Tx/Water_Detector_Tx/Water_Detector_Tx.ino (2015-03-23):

/*
Wireless Water Detector Trasnmitter
Compile on IDE 1.6.x w/panStamp patch
Board: panStamp AVR

Link to panStamp libraries on GitHub: http://git.io/pkhC
Link to panStamp Wiki, API section: http://github.com/panStamp/panstamp/wiki/panStamp-API

 
To Do:
Add transmitter name to data that's sent to panstamp - maybe 
Start Tx addresses at zero, this way in the Rx sketch, you can use an array and make the array element the Tx address. You want array to start at zero

 
Inputs:
 Wet/Dry status from sponge
 Temperature from OneWire DS18B20
 Status button - when pressed RGB LED will display status
 Address selector rotary dip switch
 
Outputs:
 3 PWM for RGB LED

Data to Transmit (10 bytes):
byte 0: Rx ID - ID of panStamp we are sending data too
byte 1: Tx ID - ID of this panStamp
byte 2: Wet/Dry Status from sponge/Op-amp. Wet = true, Dry = false
byte 3-4: Air temperature
Byte 5-6: battery voltage in milliamps. Battery voltage is measured with code, not an input pin
Byte 7-8: Spare
Byte 9: Checksum
 
panStamp will sleep for 8 second, sleepWd(), wake up and transmit data, about 0.4 seconds, then repeat.
Average current draw is 1mA (about 20mA when awake and 0.009 mA when asleep)
CR123 batteries will last several months


=== I/O ===
D3 - Status LED, Blu, PWM
D4 - Water detector - sponge with op-amp
D5 - Status LED, Grn, PWM
D6 - Status LED, Red, PWM
D8 - 1Wire temperature sensor input
D9 - Status button input
A0-3 - BCD switch for address selector

 
Change Log:
07/04/14 v2.00 - Made ledColor an enum, added spare data field and checksum
02/26/15 v2.01 - Moved voltage calibration from main sketch to this one. Changed some variable names, formatting. Support for 3rd wireless transmitter
                 Started adding support for BCD address switch.  Added code to save voltage calibration to EEPROM
03/08/15 v2.02 - Upgraded to work with latest panStamp API library. Lots of formatting and comment changes.
                 Removed readVcc() function and replaced with panstamp.getVcc().  Removed unused files: Water_detector_Tx_Library.h/cpp
                 Changed addresses of panStamps transmitters to start at 0 - bacause address ID is used in as array element number
03/09/15 v2.03 - Trying to get sketch to compile in Xcode
03/22/15 v2.04 - added print statements to voltage calibration section
*/

#define VERSION  "2.04"

const byte g_Tx_Address         = 2;  // Master Bath = 0, Guest = 1, First Floor  = 2.  SRG - delete after BCD switch is hooked up

const bool SAVE_VOLTAGE_CALIB = false; // set to true to save voltage calibration offset (g_volt_calibration) to EEPROM.  Just do this once right after calibration offset is calculated with a voltmeter
     int16_t g_volt_calibration = 25;  // Master = -71, Guest = -40, First Floor = 0


#include <Arduino.h>
#include <HardwareSerial.h>
#include <EEPROM.h>              // panStamp address is saved to EEPROM http://www.arduino.cc/en/Reference/EEPROM
#include "OneWire.h"             // http://www.pjrc.com/teensy/td_libs_OneWire.html
#include "DallasTemperature.h"   // http://milesburton.com/Main_Page?title=Dallas_Temperature_Control_Library


#define WET LOW                  // When digital input from sponge/Op-Amp is LOW, the sponge is wet
#define TEMPERATURE_PRECISION 9  // sets precision of DS18B20 1-wire temperature sensor

const byte PIN_LED_RED =          6;  // RGB LED Red, PWM pin
const byte PIN_LED_GRN =          5;  // RGB LED Green, PWM pin
const byte PIN_LED_BLU =          3;  // RGB LED Blue, PWM pin
const byte PIN_STATUS_BUTTON =    9;  // Status pushbutton input pin
const byte PIN_SPONGE  =          4;  // Input pin from op-amp connected to the sponge
const byte PIN_TEMPERATURE =      8;  // Data pin for 1-Wire temperature sensor
const byte PIN_ADDR_BCD1    =    A0;  // Rotary BCD switch pin 1
const byte PIN_ADDR_BCD2    =    A0;  // Rotary BCD switch pin 2
const byte PIN_ADDR_BCD4    =    A0;  // Rotary BCD switch pin 4
const byte PIN_ADDR_BCD8    =    A0;  // Rotary BCD switch pin 8


const byte DATA_LENGTH_PS =                10;  // number of bytes in wireless packet going to receiver
const byte CHECKSUM_BYTE = DATA_LENGTH_PS - 1;  // packet checksum (last byte in packet)
const byte EEPROM_ADDR_CALIB =            100;  // Starting EEPROM address used to store for voltage calibration offset


// Color settings for LED
// Green = volts ok, yellow = volts getting low, red = low volts, blue = water detected
enum ledColor_t { GREEN, YELLOW, RED, BLUE, WHITE };


// Setup a 1-Wire instances to communicate 1-Wire DS18B20 temperature sensor
OneWire oneWire(PIN_TEMPERATURE);
DallasTemperature tempSensor(&oneWire);


// panStamp config
const byte g_RF_Channel =               0;  // panStamp channel
      byte g_psNetworkAddress[] = {46, 0};  // panStamp network address, aka SyncWord.  Tx and Rx must have same network address
const byte g_psReceiverAddress =       99;  // panStamp receiver address
const uint16_t LOW_VOLT_LIMIT =      2500;  // Minimum millivolts that panStamp can operate.  If volts is below this, don't send data

// Function Prototypes
bool isWet();
byte getDeviceAddress();          // returns panStamp address of this transmitter by reading BCD rotary switch
void blinkLED(ledColor_t color);
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

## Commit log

2013-10-25 enabled red LED output and reed relay
2013-12-13 alert when remote sensor comes back online
2013-12-18 char twitterMsg[] was too short
    [Water_Detector_Main.ino]
2014-01-17 Eagle Files
    [Leak Detector Remote.brd, Leak Detector Remote.sch, Leak Detector v3.brd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]
2015-02-14 v2.08 Fixed heartbeat, added dehumidifier sensor
    Fixed Sunday heartbeat alert
    Added a dehumidifier sensor to one of the two spare wired inputs
    [Water_Detector_Main.ino]
2015-02-14 Eagle board files
    [Leak Detector 2B.brd, Leak Detector 2B.sch, Leak Detector Remote v1_0.brd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]
2015-02-14 v2.09 - removed PrintStates() function
    Don’t need this anymore, OLED display shows everything needed
2015-03-09 v3.0 - major changes
    Changed I2C so it requested data from a specific wireless leak
    detector. Previously the slave sent data for two detectors in one
    packet. But now that I have three, I decided to change it. Data is
    also stored in a structure array.
    [Water_Detector_Main.ino]
2015-03-09 noted I2C packet structure change
2015-03-23 v2.04 added some print statements

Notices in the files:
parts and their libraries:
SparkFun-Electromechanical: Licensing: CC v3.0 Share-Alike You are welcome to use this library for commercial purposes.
